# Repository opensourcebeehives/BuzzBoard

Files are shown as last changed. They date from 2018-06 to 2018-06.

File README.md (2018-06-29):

# BuzzBoard v1.00
Initial release of open source resources for BuzzBoard PCBA

## Feedback, Help, and Collaboration

Maintained repositories are split and located here:

Hardware: https://github.com/opensourcebeehives/BuzzBoard_hardware

Firmware: https://github.com/opensourcebeehives/BuzzBoard_firmware

Join the discussion here: [OSBeehives Forum - BuzzBoard Discussion](https://community.osbeehives.com/t/buzzboard-open-source-development-board-discussion-thread/642)

Contact us directly here: hello@osbeehives.com

## Use

See license file.

## Change Log

### v1.0
  - Initial release

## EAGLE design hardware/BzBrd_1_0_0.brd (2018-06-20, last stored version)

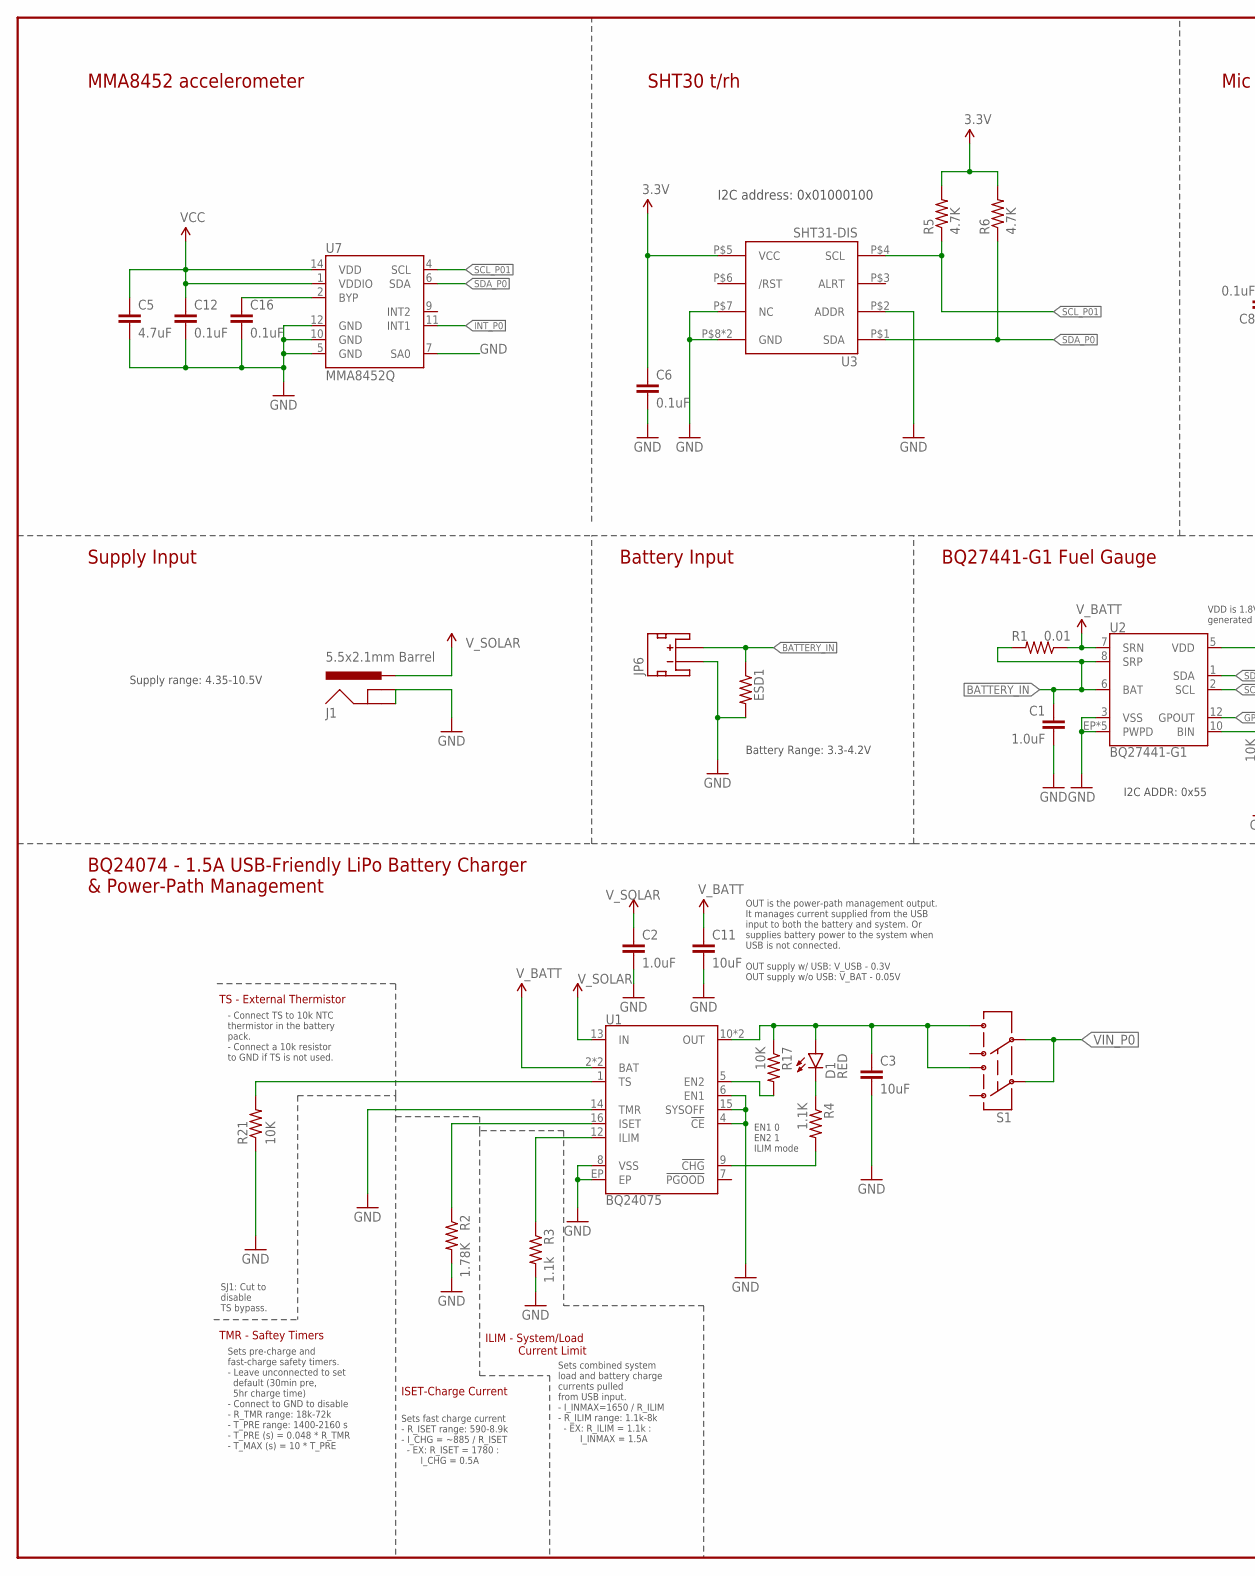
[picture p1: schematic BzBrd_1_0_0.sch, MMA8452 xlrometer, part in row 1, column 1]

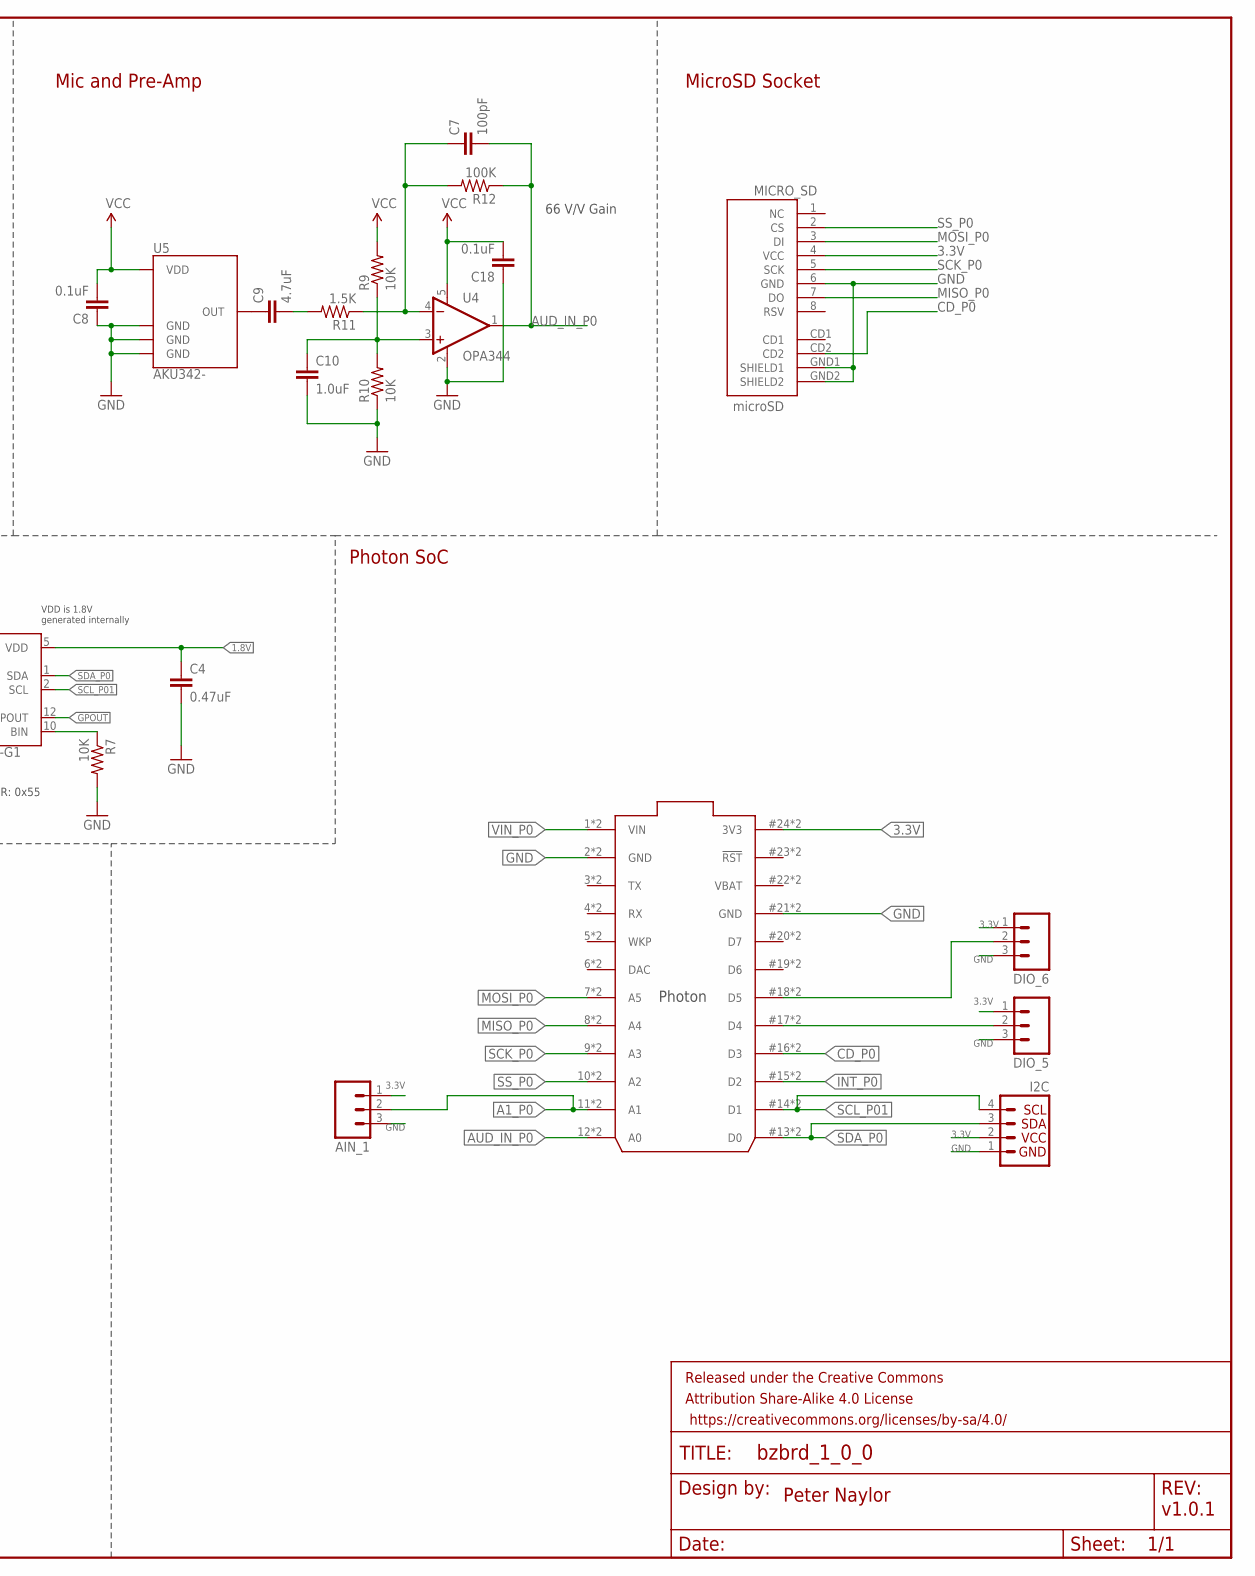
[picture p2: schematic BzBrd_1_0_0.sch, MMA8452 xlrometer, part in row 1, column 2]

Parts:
AIN_1: M03LOCK_LONGPADS; 1X03_LOCK_LONGPADS
C1, C10: 1.0uF; 0603-CAP
C2: 1.0uF; 1206-CAP
C3, C11: 10uF; 0805-CAP
C4: 0.47uF; 0603-CAP
C5, C9: 4.7uF; 0603-CAP
C6, C12, C16: 0.1uF; 0603-CAP
C7: 100pF; 0402-CAP
C8, C18: 0.1uF; 0402-CAP
D1: RED; LED-0603
DIO_5, DIO_6: M03LOCK_LONGPADS; 1X03_LOCK_LONGPADS
ESD1: R-US_R0201; R0201
FRAME1: FRAME-LEDGER; CREATIVE_COMMONS
I2C: I2C_STANDARD; 1X04
J1: 5.5x2.1mm Barrel; POWER_JACK_SMD
JP6: JST_2MM_MALE; JST-2-SMD
MICRO_SD: microSD; MICRO-SD-SOCKET-PP
R1: 0.01; 1206
R2: 1.78K; 0603-RES
R3: 1.1k; 0603-RES
R4: 1.1K; 0603-RES
R5, R6: 4.7K; 0603-RES
R7, R17, R21: 10K; 0603-RES
R9, R10: 10K; 0402-RES
R11: 1.5K; 0402-RES
R12: 100K; 0402-RES
S1: SWITCH-DPDT; JCQN
U1: BQ24075; PVQFN-N16
U2: BQ27441-G1; PDSO-N12
U3: SHT31-DIS; SHT3X
U4: OPA344; SOT23-5
U5: AKU342-
U7: MMA8452Q; QFN-16_0.5MM
U$1: PHOTON_WITH_STACKABLE_HEADERS; PHOTON_STACKABLE

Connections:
1.8V: C4.1, U2.5 (VDD)
3.3V: AIN_1.1, C5.1, C6.1, C8.2, C12.1, C18.2, DIO_5.1, DIO_6.1, I2C.2, MICRO_SD.4 (VCC), R5.2, R6.2, R9.2, U3.P$5 (VCC), U4.5 (V+), U5.4 (VDD), U7.1 (VDDIO), U7.14 (VDD), U$1.24 (3V3), U$1.#24 (3V3)
!CHG!: R4.2, U1.9 (!CHG!)
A1_P0: AIN_1.2, U$1.11 (A1), U$1.@11 (A1)
AUD_IN_P0: C7.2, R12.1, U4.1 (OUT), U$1.12 (A0), U$1.@12 (A0)
BATTERY_IN: C1.1, ESD1.1, JP6.2 (+), R1.2, U2.6 (BAT), U2.8 (SRP)
CD_P0: MICRO_SD.CD2, U$1.16 (D3), U$1.#16 (D3)
GND: AIN_1.3, C1.2, C2.2, C3.2, C4.2, C5.2, C6.2, C8.1, C10.2, C11.2, C12.2, C16.2, C18.1, DIO_5.3, DIO_6.3, ESD1.2, I2C.1, J1.GND (GNDBREAK), J1.P$4 (GND), JP6.1 (-), MICRO_SD.6 (GND), MICRO_SD.GND1 (SHIELD1), MICRO_SD.GND2 (SHIELD2), R2.2, R3.2, R7.2, R10.1, R21.1, U1.4 (!CE!), U1.6 (EN1), U1.8 (VSS), U1.14 (TMR), U1.15 (SYSOFF), U1.EP, U2.3 (VSS), U2.EP (PWPD), U2.EP1 (PWPD), U2.EP2 (PWPD), U2.EP3 (PWPD), U2.EP4 (PWPD), U3.P$2 (ADDR), U3.P$7 (NC), U3.P$8 (GND), U3.PAD (GND), U4.2 (V-), U5.2 (GND), U5.3 (GND), U5.5 (GND), U7.5 (GND), U7.7 (SA0), U7.10 (GND), U7.12 (GND), U$1.2 (GND), U$1.21 (GND), U$1.#21 (GND), U$1.@2 (GND)
GPOUT: U2.12 (GPOUT)
ILIM: R3.1, U1.12 (ILIM)
INT_P0: U7.11 (INT1), U$1.15 (D2), U$1.#15 (D2)
ISET: R2.1, U1.16 (ISET)
MISO_P0: MICRO_SD.7 (DO), U$1.8 (A4), U$1.@8 (A4)
MOSI_P0: MICRO_SD.3 (DI), U$1.7 (A5), U$1.@7 (A5)
unnamed: D1.C, R4.1
unnamed: R7.1, U2.10 (BIN)
unnamed: R17.2, U1.5 (EN2)
unnamed: C16.1, U7.2 (BYP)
unnamed: C9.1, U5.1 (OUT)
unnamed: C7.1, R11.1, R12.2, U4.4 (-IN)
unnamed: C9.2, R11.2
unnamed: C10.1, R9.1, R10.2, U4.3 (+IN)
unnamed: DIO_5.2, U$1.17 (D4), U$1.#17 (D4)
unnamed: DIO_6.2, U$1.18 (D5), U$1.#18 (D5)
SCK_P0: MICRO_SD.5 (SCK), U$1.9 (A3), U$1.@9 (A3)
SCL_P01: I2C.4, R5.1, U2.2 (SCL), U3.P$4 (SCL), U7.4 (SCL), U$1.14 (D1), U$1.#14 (D1)
SDA_P0: I2C.3, R6.1, U2.1 (SDA), U3.P$1 (SDA), U7.6 (SDA), U$1.13 (D0), U$1.#13 (D0)
SS_P0: MICRO_SD.2 (CS), U$1.10 (A2), U$1.@10 (A2)
TS: R21.2, U1.1 (TS)
VBAT: U$1.22 (VBAT), U$1.#22 (VBAT)
VIN_P0: S1.P$2 (2), S1.P$5 (5), U$1.1 (VIN), U$1.@1 (VIN)
VOUT_SOL: C3.1, D1.A, R17.1, S1.P$3 (3), S1.P$6 (6), U1.10 (OUT), U1.11 (OUT)
V_BATT: C11.1, R1.1, U1.2 (BAT), U1.3 (BAT), U2.7 (SRN)
V_SOLAR: C2.1, J1.VIN0 (PWR), U1.13 (IN)

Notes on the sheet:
Sets fast charge current - R_ISET range: 590-8.9k - I_CHG = ~885 / R_ISET - EX: R_ISET = 1780 : I_CHG = 0.5A
Sets combined system load and battery charge currents pulled from USB input. - I_INMAX=1650 / R_ILIM - R_ILIM range: 1.1k-8k - EX: R_ILIM = 1.1k : I_INMAX = 1.5A
Supply Input
Battery Input
BQ24074 - 1.5A USB-Friendly LiPo Battery Charger & Power-Path Management
BQ27441-G1 Fuel Gauge
Peter Naylor
SJ1: Cut to disable TS bypass.
ILIM - System/Load Current Limit
ISET-Charge Current
TMR - Saftey Timers
Sets pre-charge and fast-charge safety timers. - Leave unconnected to set default (30min pre, 5hr charge time) - Connect to GND to disable - R_TMR range: 18k-72k - T_PRE range: 1400-2160 s - T_PRE (s) = 0.048 * R_TMR - T_MAX (s) = 10 * T_PRE
TS - External Thermistor
- Connect TS to 10k NTC thermistor in the battery pack. - Connect a 10k resistor to GND if TS is not used.
Supply range: 4.35-10.5V
VDD is 1.8V generated internally
OUT is the power-path management output. It manages current supplied from the USB input to both the battery and system. Or supplies battery power to the system when USB is not connected. OUT supply w/ USB: V_USB - 0.3V OUT supply w/o USB: V_BAT - 0.05V
I2C ADDR: 0x55
Battery Range: 3.3-4.2V
EN1 0 EN2 1 ILIM mode
I2C address: 0x01000100
66 V/V Gain
Mic and Pre-Amp
SHT30 t/rh
MMA8452 accelerometer
Photon SoC
MicroSD Socket
v1.0.1

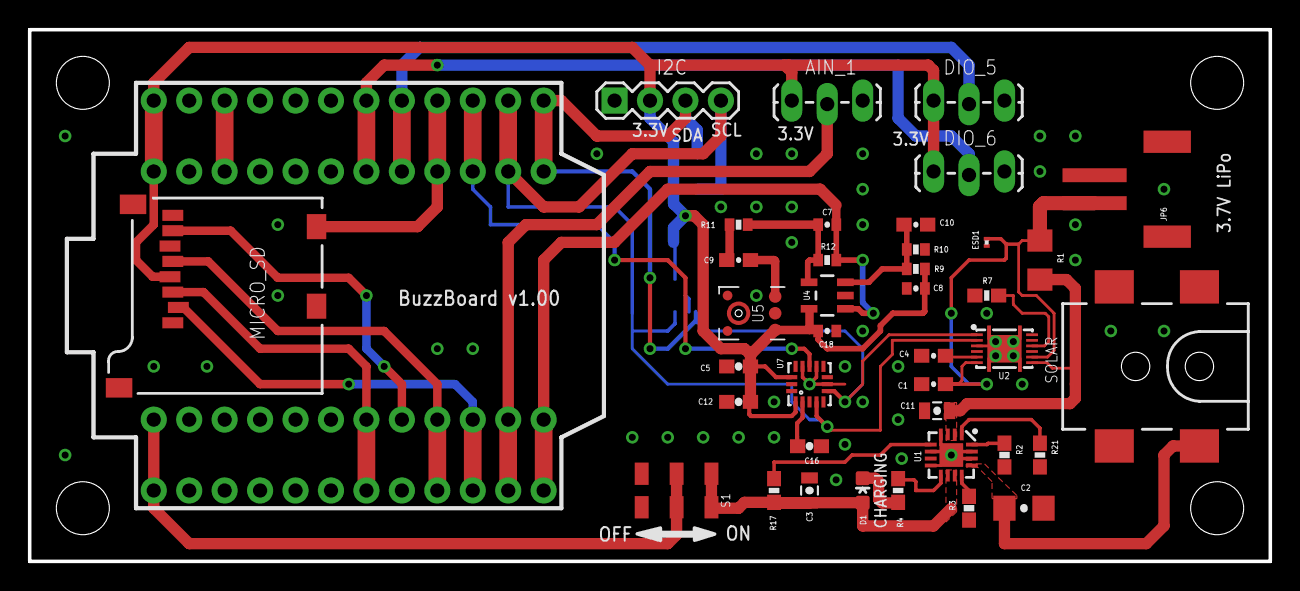
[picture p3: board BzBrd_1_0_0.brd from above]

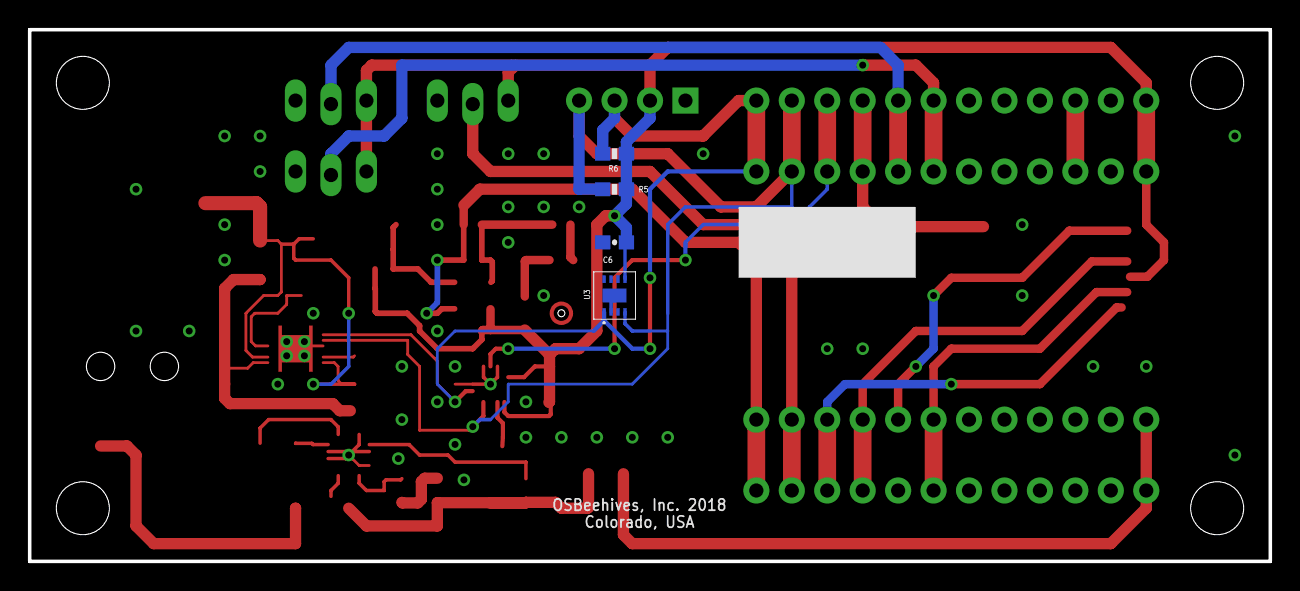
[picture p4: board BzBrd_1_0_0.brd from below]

Board: 2 copper layers, 88.9 x 38.1 mm, 49 parts (4 on the bottom side), 33 nets.

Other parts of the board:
U$2, U$3, U$4, U$5: STAND-OFF

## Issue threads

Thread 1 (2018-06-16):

Seperate repository

mojoaxel, 2018-06-16:
First! 🐝

I would recommend creating two repositories e.g. "BuzzBoard-Hardware" and "BuzzBoard-Firmware". I see the following benefits:
* The have different licenses. It makes sense to seperate the at a early stage to also seperate the licenses. At the moment is not really clear.
* Different Communities can develop: Firmware developers are maybe not so interested in changes in the hardware/and vise versa.
* The use of github tags and source-type-recognition would work better.

pnaylor1982, 2018-06-29:
Done, new repos linked in README

mojoaxel, 2018-06-29:
:clap: thx

Closed 2018-06-29.

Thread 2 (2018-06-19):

Add board diagrams that work on Free Version of Eagle CAD

bennmapes, 2018-06-19:
When I try to open the schematic or board diagrams in Eagle I get the following error:

```
The free edition of EAGLE can't perform the requested action!

There are not enough sheets.
```

If possible could you export a version of the board that is flattened into two schematic sheets and no more than 2 signal or plane layers. Here is a reference to the available features of the free version https://www.autodesk.com/compare/eagle-vs-eagle-premium .

If not possible just close this issue.

pnaylor1982, 2018-06-20:
Combined into one sheet

Closed 2018-06-20.

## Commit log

2018-06-20 one schematic sheet
    [BzBrd_1_0_0.brd, BzBrd_1_0_0.sch]
2018-06-29 moved repos
    [BzBrd_1_0_0.brd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]

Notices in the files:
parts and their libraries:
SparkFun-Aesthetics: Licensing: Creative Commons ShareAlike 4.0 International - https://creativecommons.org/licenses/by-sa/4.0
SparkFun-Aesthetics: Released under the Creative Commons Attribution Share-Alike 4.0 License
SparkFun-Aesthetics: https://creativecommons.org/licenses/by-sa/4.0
